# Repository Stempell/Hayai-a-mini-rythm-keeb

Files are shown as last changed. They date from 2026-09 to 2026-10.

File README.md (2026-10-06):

Banner3

Hayai is a Mini keyboard for shortcuts and playing rythm games. It features 4 magnetic hall effect switches (each with an rgb underglow LED) a rotary encoder and an 0.96" IPS display.
The display is connected by a FPC cable to a ZIF socket. custom footprints are in the kicad files.
The whole thing runs on a rp2040.

Here's how it looks:
Hayai

Hayai is desing around the Gateron magnetic jade air he dimensions but you can really use any magnetic switch you want, thanks to it's easy hotswap 

obraz

## Schematic
Zrzut ekranu 2026-09-25 191601

## PCB
obraz

dimensions of the pcb(and the acrylic plates) are roughly 84,5 x 48,7mm.

## Casing method
I took inspiration from the sayo device with the casing method with the pcb being sandwitched between the plates. I decided on a system where 4 holes will be occupied by screws attached from both sides to a female to female spacer, and the other 2 by dowel pins to prevent the plates from wobbling sideways.

Zrzut ekranu 2026-09-25 234834

The pcb sits inbetween the two middle plates with cutouts for components and pins

## Assembly
To assemble Hayai you'll need to follow these 4 simple steps:
1. Solder on all of the necesary components (you will have a bit less work to do if you choose pcba) The mcu can come with header pins pre-soldered on so you can make your job a bit easier for a like a dollar
2. Connect the display via the fpc cable with the panel facing upwards from the pcb and lay it flat on the board.
3. Sandwitch the pcb between the plates (look at the 3d model if you need some guidance) and put M3 dowel pins into the middle holes on the sides.
4. put M2 standoffs into the corner holes and screw them in with M2. this should hold the plates together. You can also add washers under the screws so it holds the plates better, M3 should fit.

Have fun! C:

## Bill of Materials

| # | Item | Quantity | Price | Link |
|---:|---|---:|---:|---|
| 1 | Custom PCB | 1 | ~$22.87 | [JLCPCB](https://jlcpcb.com/) |
| 2 | Acrylic plates | 4 | ~$18.04 | [Elecrow](https://www.elecrow.com/) |
| 3 | GATERON Magnetic Jade Air HE Switches | 4 | $15.00 | [GATERON](https://pl.aliexpress.com/item/1005005513800132.html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) |
| 4 | Keycaps of choice | 4 | $1.34 | [AliExpress](https://pl.aliexpress.com/item/4000473863693.html) |
| 5 | 0.96" IPS TFT ST7735 display | 1 | $1.62 | [BuyDisplay](https://www.buydisplay.com/0-96-inch-mini-color-tft-lcd-display-module-80x160-ips-tft-st7735) |
| 6 | EC11 20mm switch rotary encoder with mounting plates (the cap i chose fits the one with a plum handle) | 1 | $1.38 | [AliExpress](https://pl.aliexpress.com/item/1005007644083514.html) |
| 7 | Encoder cap of choice | 1 | $3.24 | [AliExpress](https://pl.aliexpress.com/item/1005008583446552.html) |
| 8 | Waveshare RP2350-Zero Mini Development Board Female | 1 | $5.79 | [Waveshare](https://www.waveshare.com/rp2350-zero.htm) |
| 9 | 1x9 pin header for microcontroller | 2 | $2.45 | [AliExpress](https://tinyurl.com/3yzm8hka) |
| 10 | DRV5056A4QDBZR (SOT-23-3) | 4 | $3.36 | [JLCPCB](https://jlcpcb.com/partdetail/TexasInstruments-DRV5056A4QDBZR/C2152902) |
| 11 | Brass standoffs (M2, 13mm) | 4 | $3.28 | [AliExpress](https://pl.aliexpress.com/item/1005012002279754.html) |
| 12 | Dowel pins (M3, 14mm) | 4 | $4.11 | [AliExpress](https://pl.aliexpress.com/item/4000473863693.html) |
| 13 | M2 screws, can also add washers | 4 |  |  |
| 14 | SK6812-MINI-E LEDs | 4 | $2.01 | [AliExpress](https://pl.aliexpress.com/item/1005008308801366.html) |

Subtotal : $84.40

Note that the pcb and plates were made around these specific parts. You can experiment and switch them out for different models but i don't guarantee it'll work

## BIll of materials for the pcba assembly

| Designator | Comment | Footprint | JLCPCB Part # | Manufacturer | Lib Type | Qty | Price |
|---|---|---|---|---|---|---|---|
| C17 | 10uF | 0402 | [C15525](https://jlcpcb.com/partdetail/16204-CL05A106MQ5NUNC/C15525)| Samsung Electro-Mechanics | Basic | 2 | $0.0512 |
| C18,C19,C20,C21,C22,C24,C25,C26,C27 | 0.1uF | 0402 | [C1525](https://jlcpcb.com/partdetail/1877-CL05B104KO5NNNC/C1525) | Samsung Electro-Mechanics | Basic | 18 | $0.0810 |
| R5 | 18Ω | 0402 | [C25084](https://jlcpcb.com/partdetail/25827-0402WGF180JTCE/C25084) | UNI-ROYAL (Uniroyal Elec) | Extended | 20 | $0.0480 |
| R7 | 10kΩ | 0402 | [C25744](https://jlcpcb.com/partdetail/26487-0402WGF1002TCE/C25744) | UNI-ROYAL (Uniroyal Elec) | Basic | 2 | $0.0068 |
| U4 | ZIF connector, 8-pin, 0.5mm | ZIF_connector8pin0,5mm | [C2856828](https://jlcpcb.com/partdetail/XUNPU-FPC_05FB8PH20/C2856828) | XUNPU | Extended | 2 | $0.3208 |
|

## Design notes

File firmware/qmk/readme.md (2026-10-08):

# hayai

hayai

*A short description of the keyboard/project*

* Keyboard Maintainer: [Wiktor Stepien](https://github.com/Stempell)
* Hardware Supported: *The PCBs, controllers supported*
* Hardware Availability: *Links to where you can find this hardware*

Make example for this keyboard (after setting up your build environment):

    make hayai:default

Flashing example for this keyboard:

    make hayai:default:flash

See the [build environment setup](https://docs.qmk.fm/#/getting_started_build_tools) and the [make instructions](https://docs.qmk.fm/#/getting_started_make_guide) for more information. Brand new to QMK? Start with our [Complete Newbs Guide](https://docs.qmk.fm/#/newbs).

## Bootloader

Enter the bootloader in 3 ways:

* **Bootmagic reset**: Hold down the key at (0,0) in the matrix (usually the top left key or Escape) and plug in the keyboard
* **Physical reset button**: Briefly press the button on the back of the PCB - some may have pads you must short instead
* **Keycode in layout**: Press the key mapped to `QK_BOOT` if it is available

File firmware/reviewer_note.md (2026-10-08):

Hi! i purposly did not add a finished firmware yet as i need the phisicaly bulid project to test the display, calibrate the switches, ect. I'll finish the firmware as soon as i am able to do so based on irl calibrations!

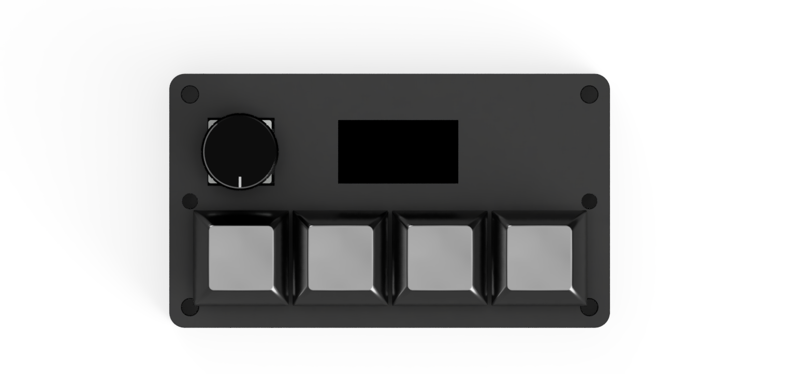
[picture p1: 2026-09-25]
Photos/Top view.png

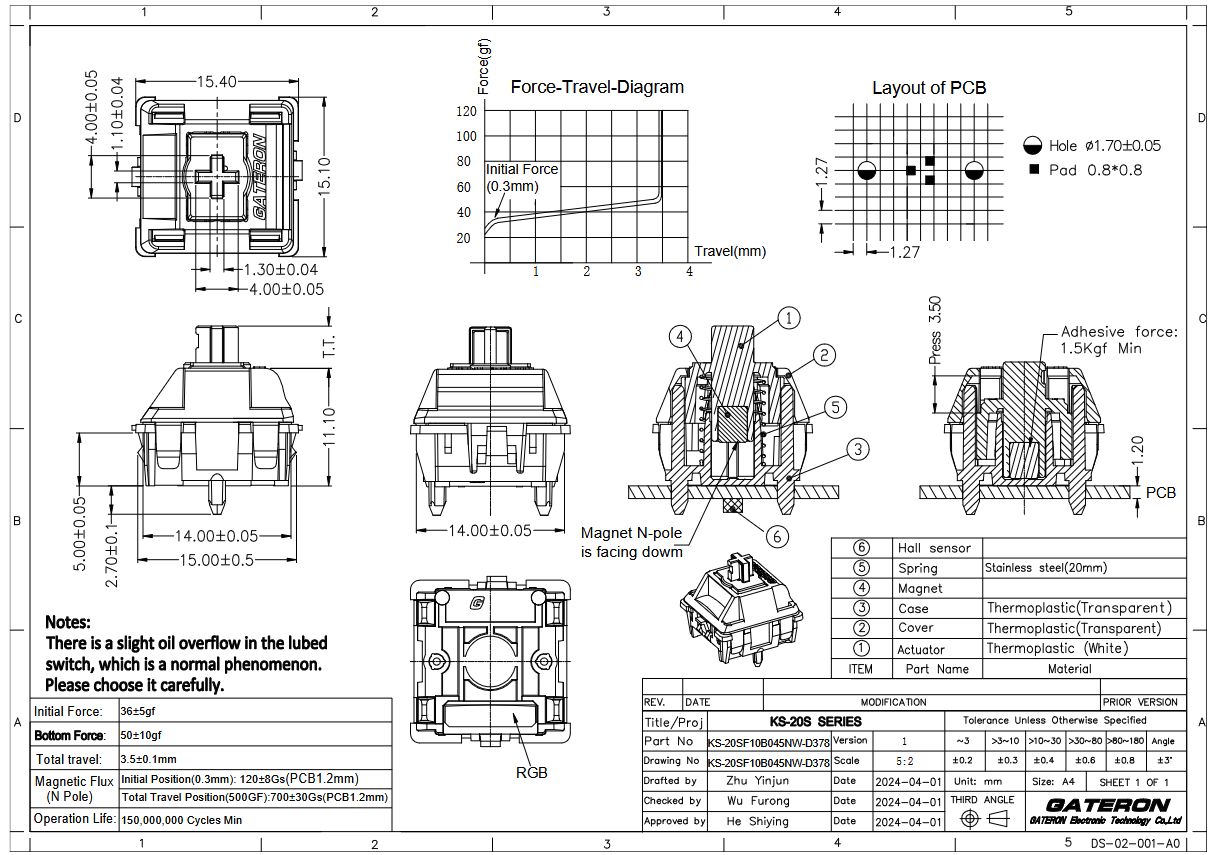
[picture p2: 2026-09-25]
Photos/Zrzut ekranu 2026-08-28 192311.png

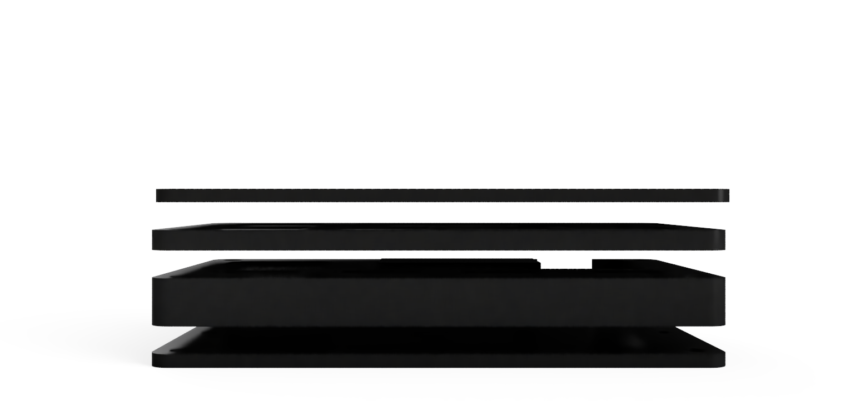
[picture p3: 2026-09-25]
Photos/plates1.png

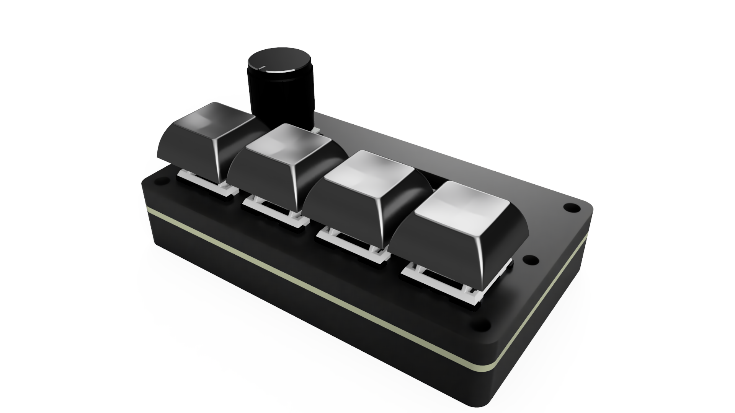
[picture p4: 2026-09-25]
Photos/Hayai.png

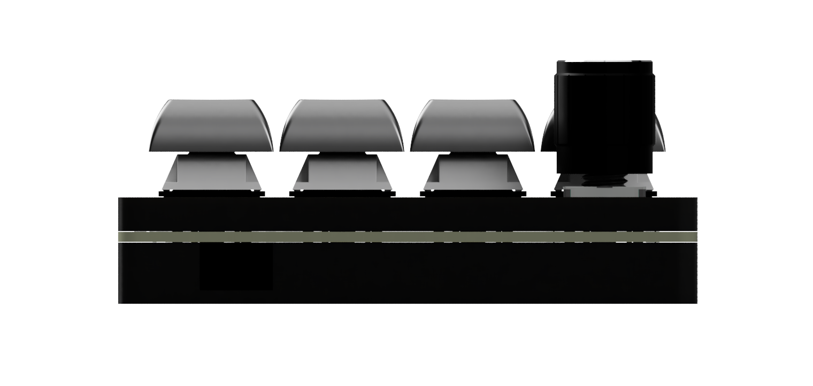
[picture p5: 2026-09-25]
Photos/Back view.png

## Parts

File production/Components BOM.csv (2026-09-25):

# | Item | Quantity | Price (USD) | Source
1 | Custom PCB | 1 | ~$22.87 | https://jlcpcb.com/
2 | Acrylic plates | 4 | ~$18.04 | https://www.elecrow.com/
3 | GATERON Magnetic Jade Air HE Switches | 4 | $15.00 | https://www.gateron.com/products/gateron-magnetic-jade-air-he-switch-set?VariantsId=11190
4 | Keycaps of choice | 4 | — | —
5 | 0.96" IPS TFT ST7735 display | 1 | $1.62 | https://www.buydisplay.com/0-96-inch-mini-color-tft-lcd-display-module-80x160-ips-tft-st7735
6 | EC11 20mm switch rotary encoder | 1 | ~$1.80 | —
7 | Encoder cap of choice | 1 | — | —
8 | Waveshare RP2350-Zero Mini Development Board Female | 1 | $5.79 | https://www.waveshare.com/rp2350-zero.htm
9 | 1x9 pin header for microcontroller | 2 | $2.45 | https://tinyurl.com/3yzm8hka
10 | DRV5056A4QDBZR (SOT-23-3) | 4 | $3.36 | https://www.digikey.com/en/products/detail/texas-instruments/DRV5056A4QDBZR/9692623
11 | Brass standoffs (2M, 13mm) | 4 | $3.28 | https://pl.aliexpress.com/item/1005012002279754.html
12 | Dowel pins (3M, 14mm) | 4 | $4.11 | https://pl.aliexpress.com/item/4000473863693.html
13 | M2 screws, can also add washers | 4 | — | —

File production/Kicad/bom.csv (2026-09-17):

Designator | Footprint | Quantity | Value | LCSC Part #
C17 | 0402 | 1 | 10uF
C18, C19, C20, C21, C22, C24, C25, C26, C27 | 0402 | 9 | 0.1uF
D1, D2, D3, D4 | LED_SK6812MINI-E_3.2x2.8mm_P1.5mm_ReverseMount | 4 | SK6812MINI-E
R5 | 0402 | 1 | 18Ω
R7 | 0402 | 1 | 10kΩ
SW1 | RotaryEncoder_Alps_EC11E-Switch_Vertical_H20mm_MountingHoles | 1 | RotaryEncoder_Switch_MP
U1 | Waveshare_RP2040-Zero_THT | 1 | ~
U4 | ZIF_connector 8 pin 0,5mm | 1 | ~
U5, U6, U7, U8 | SOT-23 | 4 | DRV5055A4xDBZxQ1

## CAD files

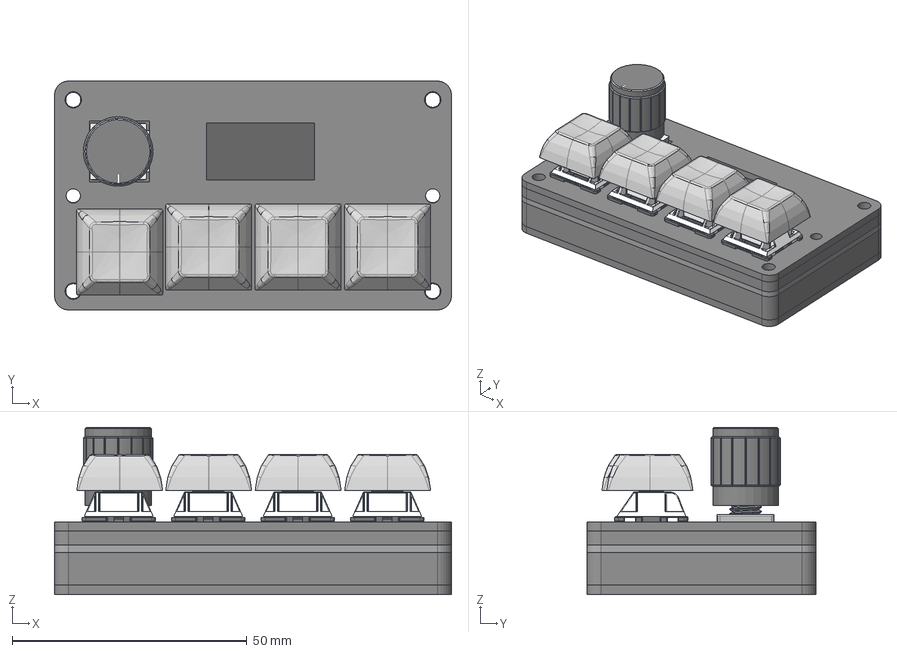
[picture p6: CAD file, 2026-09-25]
3D models/Hayai/Hayai full bulid V1.step
84.5 x 48.7 x 35.6 mm
C_0402_1005Metric x 10
R_0402_1005Metric x 2
MX_PCB x 4
Pin1 x 4
Pin2 x 4
Pin3 x 4
Pin4 x 4
EC11
SOT-23 x 4
HayaiAlt_copper
HayaiAlt_pad
HayaiAlt_via
HayaiAlt_silkscreen
HayaiAlt_silkscreen_1
HayaiAlt_soldermask
HayaiAlt_soldermask_1
HayaiAlt_PCB
keycap2 x 4
encoder cap

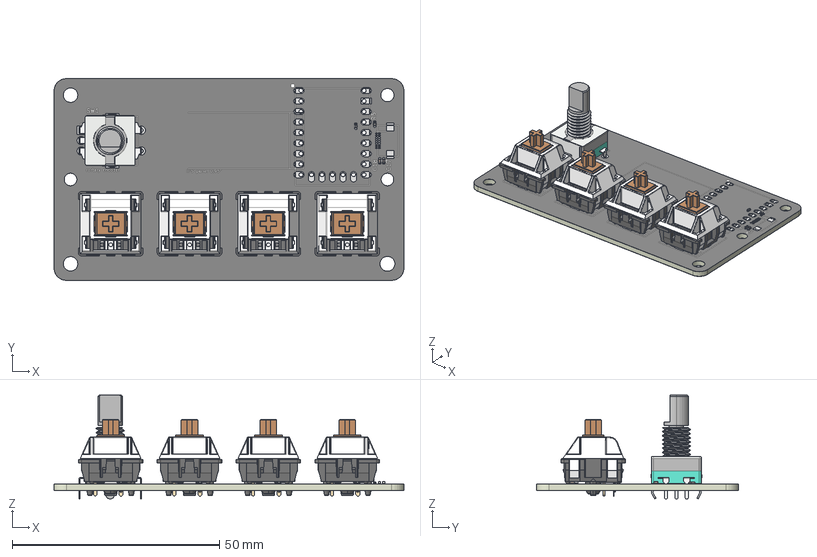
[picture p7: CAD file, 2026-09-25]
3D models/Hayai/pcb.step
84.5 x 48.7 x 25.1 mm
C_0402_1005Metric x 10
R_0402_1005Metric x 2
MX_PCB x 4
Pin1 x 4
Pin2 x 4
Pin3 x 4
Pin4 x 4
EC11
SOT-23 x 4
HayaiAlt_copper
HayaiAlt_pad
HayaiAlt_via
HayaiAlt_silkscreen x 2
HayaiAlt_soldermask x 2
HayaiAlt_PCB

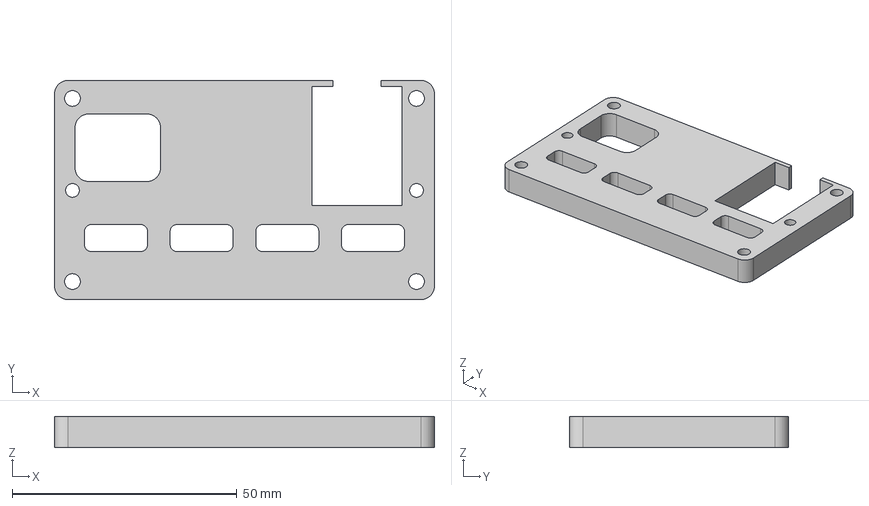
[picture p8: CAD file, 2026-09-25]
3D models/Plates/Hayai Lower midplate.step
84.5 x 48.7 x 7.00 mm

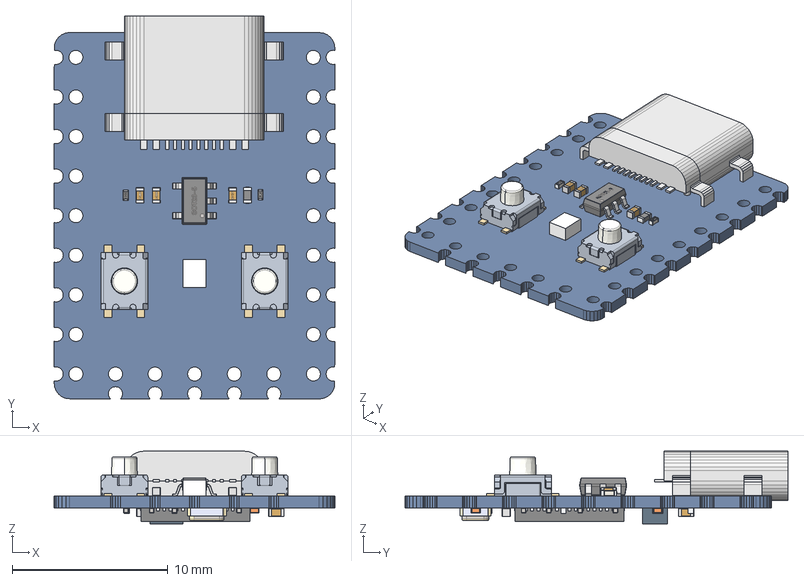
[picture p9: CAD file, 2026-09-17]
3D models/RP2350_Zero_step/RP2350-Zero.step
18.0 x 24.6 x 4.66 mm
Board
User_Library-TYPE-C-31-M-14
3_1_A x 7
User_Library-0201(0603M)_Cap x 12
ts-1185ec-a-e-a-1 x 2
Extruded x 2
User_Library-RES_0603-0201 x 8
User_Library-RP2350A
SOT23-5AND6_00 x 5
SOT23-5-14065_AF0
User_Library-SM2520-4
L0402

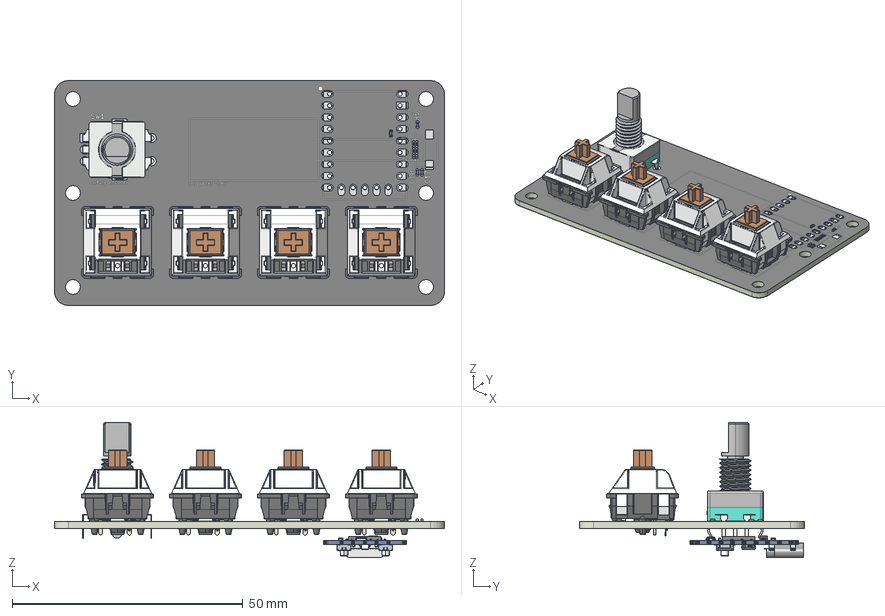
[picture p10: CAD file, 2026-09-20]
KiCad Files/hayai.step
84.5 x 48.7 x 29.3 mm
C_0402_1005Metric x 10
R_0402_1005Metric x 2
MX_PCB x 4
Pin1 x 4
Pin2 x 4
Pin3 x 4
Pin4 x 4
EC11
SOT-23 x 4
Board
User_Library-TYPE-C-31-M-14
3_1_A x 7
User_Library-0201(0603M)_Cap x 12
ts-1185ec-a-e-a-1 x 2
Extruded x 2
User_Library-RES_0603-0201 x 8
User_Library-RP2350A
SOT23-5AND6_00 x 5
SOT23-5-14065_AF0
User_Library-SM2520-4
L0402
HayaiAlt_copper
HayaiAlt_pad
HayaiAlt_via
HayaiAlt_silkscreen x 2
HayaiAlt_soldermask x 2
HayaiAlt_PCB

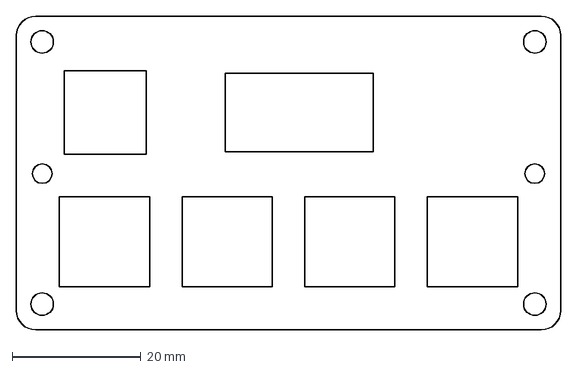
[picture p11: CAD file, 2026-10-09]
production/Plates dxf's/Top-plate.dxf
84.5 x 48.7 mm

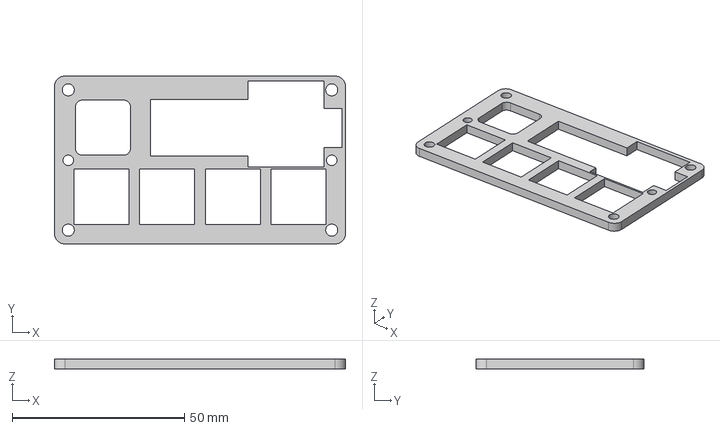
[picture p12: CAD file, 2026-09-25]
3D models/Plates/Hayai Upper midplate.step
84.5 x 48.7 x 3.00 mm

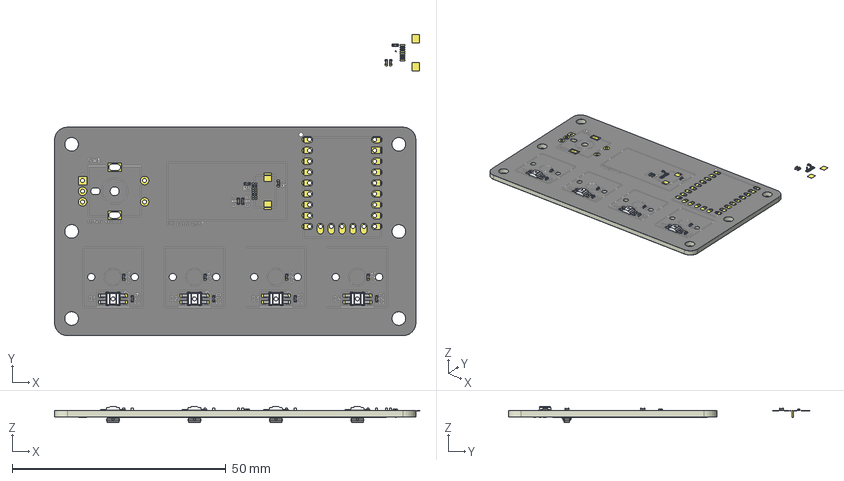
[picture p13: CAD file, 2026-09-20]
KiCad Files/.step
85.4 x 70.4 x 3.82 mm
C_0402_1005Metric x 12
Pin1 x 4
Pin2 x 4
Pin3 x 4
Pin4 x 4
R_0402_1005Metric x 3
SOT-23 x 4
HayaiAlt_copper
HayaiAlt_silkscreen x 2
HayaiAlt_soldermask x 2
HayaiAlt_PCB

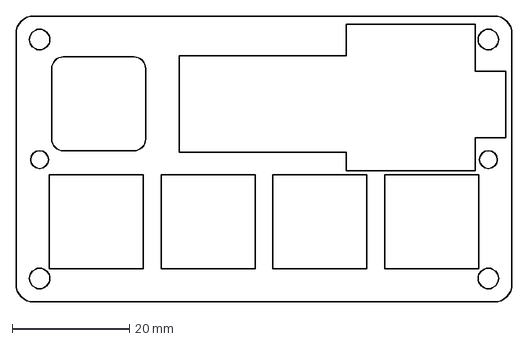
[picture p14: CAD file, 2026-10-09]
production/Plates dxf's/Upper-midplate.dxf
84.5 x 48.7 mm

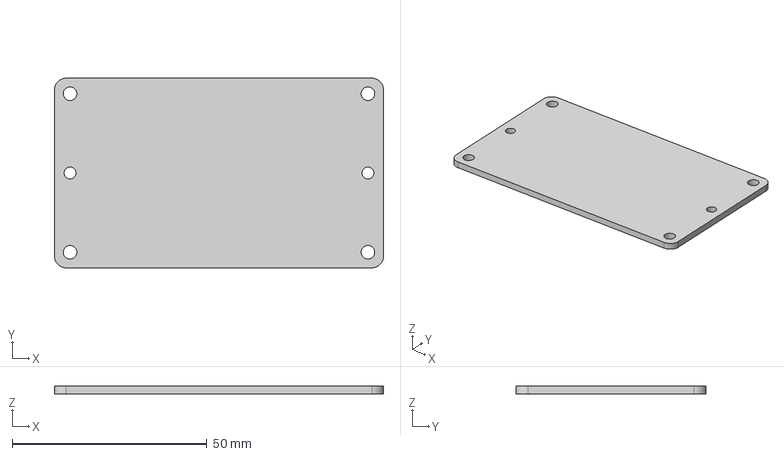
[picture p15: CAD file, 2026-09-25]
3D models/Plates/Hayai Bottom plate.step
84.5 x 48.7 x 2.00 mm

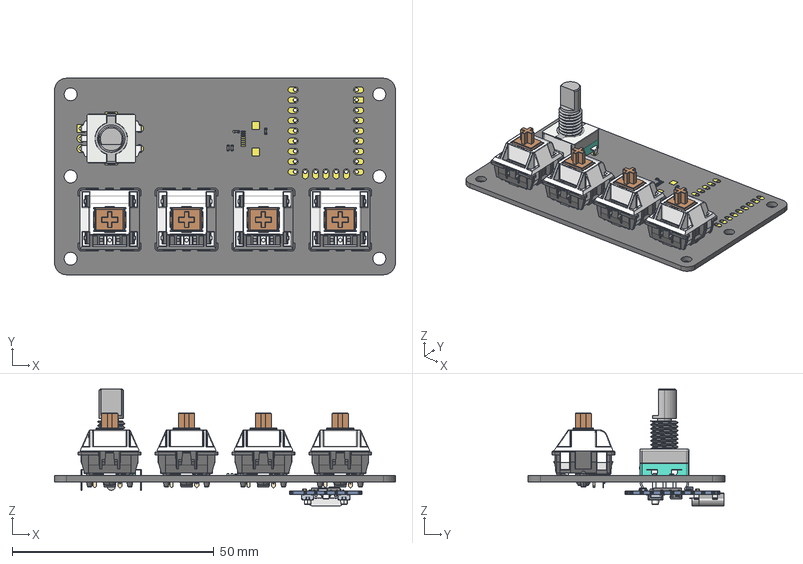
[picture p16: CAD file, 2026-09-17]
KiCad Files/HayaiAlt.step
84.5 x 48.7 x 29.0 mm
C_0402_1005Metric x 10
SW_Cherry_MX_PCB_cp x 4
Pin1 x 4
Pin2 x 4
Pin3 x 4
Pin4 x 4
R_0402_1005Metric x 2
ѽת±ძǷ
SOT-23 x 4
Board
User_Library-TYPE-C-31-M-14
3_1_A x 7
User_Library-0201(0603M)_Cap x 12
ts-1185ec-a-e-a-1 x 2
Extruded x 2
User_Library-RES_0603-0201 x 8
User_Library-RP2350A
SOT23-5AND6_00 x 5
SOT23-5-14065_AF0
User_Library-SM2520-4
L0402
HayaiAlt_copper
HayaiAlt_PCB

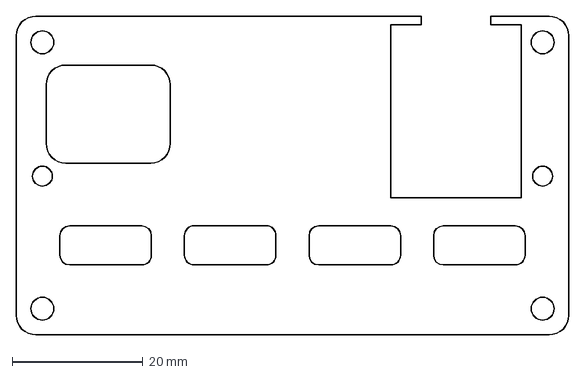
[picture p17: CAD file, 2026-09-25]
production/Plates dxf's/Lower-midplate.dxf
84.5 x 48.7 mm

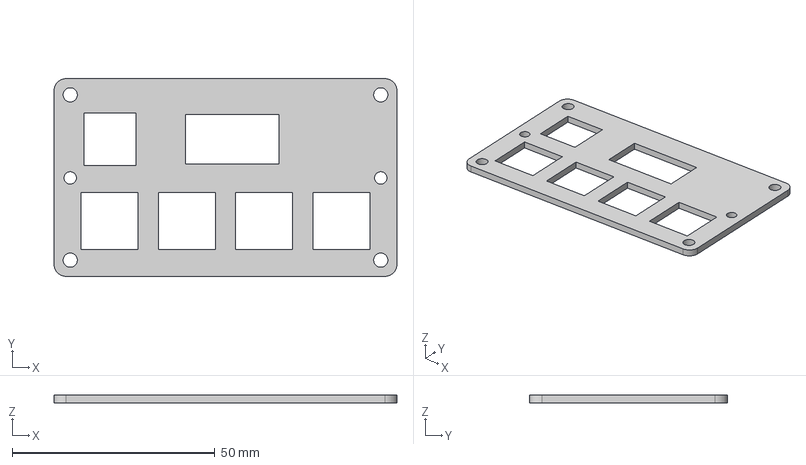
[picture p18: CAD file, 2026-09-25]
3D models/Plates/Hayai Top plate.step
84.5 x 48.7 x 2.00 mm

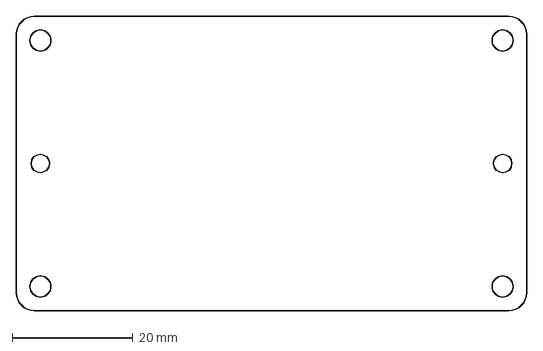
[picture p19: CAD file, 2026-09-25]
production/Plates dxf's/Bottom-plate.dxf
84.5 x 48.7 mm

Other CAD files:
3D models/Fusion_Source/Hayai full bulid V1.f3z
3D models/Fusion_Source/Plates/Hayai Bottom plate.f3d
3D models/Fusion_Source/Plates/Hayai Lower midplate.f3d
3D models/Fusion_Source/Plates/Hayai Top plate.f3d.f3d
3D models/Fusion_Source/Plates/Hayai Upper midplate.f3d
production/Plates dxf's/Bottom Plate.dxf
production/Plates dxf's/Lower Midplate.dxf
production/Plates dxf's/Top Plate.dxf
production/Plates dxf's/Upper Midplate.dxf

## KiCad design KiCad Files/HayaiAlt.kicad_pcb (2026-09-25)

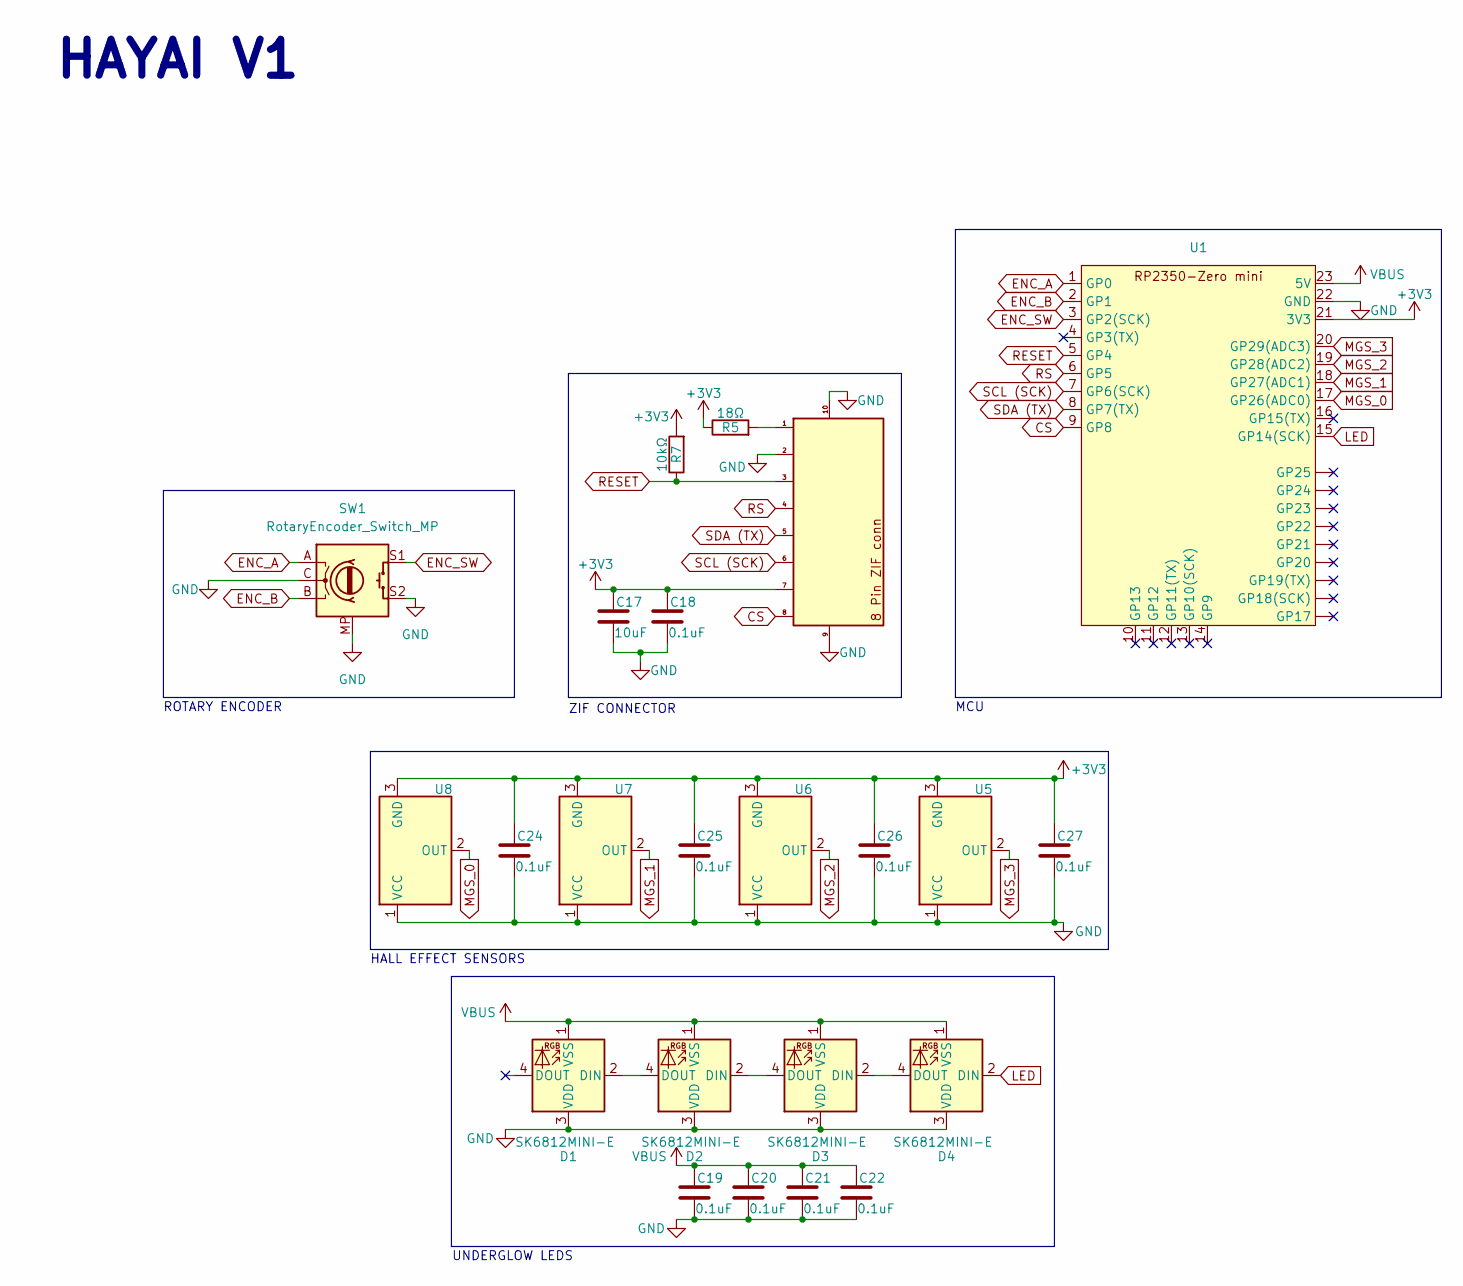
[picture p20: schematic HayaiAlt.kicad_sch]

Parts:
C17: 10uF; C_0402_1005Metric
C18, C19, C20, C21, C22, C24, C25, C26, C27: 0.1uF; C_0402_1005Metric
D1, D2, D3, D4: SK6812MINI-E; LED_SK6812MINI-E_3.2x2.8mm_P1.5mm_ReverseMount
R5: 18Ω; R_0402_1005Metric
R7: 10kΩ; R_0402_1005Metric
SW1: RotaryEncoder_Switch_MP; RotaryEncoder_Alps_EC11E-Switch_Vertical_H20mm_MountingHoles
U1: Waveshare_RP2040-Zero_THT
U4: ZIF_connector 8 pin 0,5mm
U5, U6, U7, U8: DRV5055A4xDBZxQ1; SOT-23

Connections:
+3V3: C17.1, C18.1, C24.1, C25.1, C26.1, C27.1, R5.1, R7.2, U1.21 (3V3), U4.7, U5.3 (GND), U6.3 (GND), U7.3 (GND), U8.3 (GND)
CS: U1.9 (GP8), U4.8
ENC_A: SW1.A, U1.1 (GP0)
ENC_B: SW1.B, U1.2 (GP1)
ENC_SW: SW1.S1, U1.3 (GP2(SCK))
GND: C17.2, C18.2, C19.2, C20.2, C21.2, C22.2, C24.2, C25.2, C26.2, C27.2, D1.3 (VDD), D2.3 (VDD), D3.3 (VDD), D4.3 (VDD), SW1.C, SW1.MP, SW1.S2, U1.22 (GND), U4.2, U4.9, U4.10, U5.1 (VCC), U6.1 (VCC), U7.1 (VCC), U8.1 (VCC)
LED: D4.2 (DIN), U1.15 (GP14(SCK))
MGS_0: U1.17 (GP26(ADC0)), U8.2 (OUT)
MGS_1: U1.18 (GP27(ADC1)), U7.2 (OUT)
MGS_2: U1.19 (GP28(ADC2)), U6.2 (OUT)
MGS_3: U1.20 (GP29(ADC3)), U5.2 (OUT)
unnamed: D1.2 (DIN), D2.4 (DOUT)
unnamed: D2.2 (DIN), D3.4 (DOUT)
unnamed: D3.2 (DIN), D4.4 (DOUT)
unnamed: R5.2, U4.1
RESET: R7.1, U1.5 (GP4), U4.3
RS: U1.6 (GP5), U4.4
SCL (SCK): U1.7 (GP6(SCK)), U4.6
SDA (TX): U1.8 (GP7(TX)), U4.5
VBUS: C19.1, C20.1, C21.1, C22.1, D1.1 (VSS), D2.1 (VSS), D3.1 (VSS), D4.1 (VSS), U1.23 (5V)

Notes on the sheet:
HAYAI V1
ZIF CONNECTOR
ROTARY ENCODER
UNDERGLOW LEDS
MCU
HALL EFFECT SENSORS

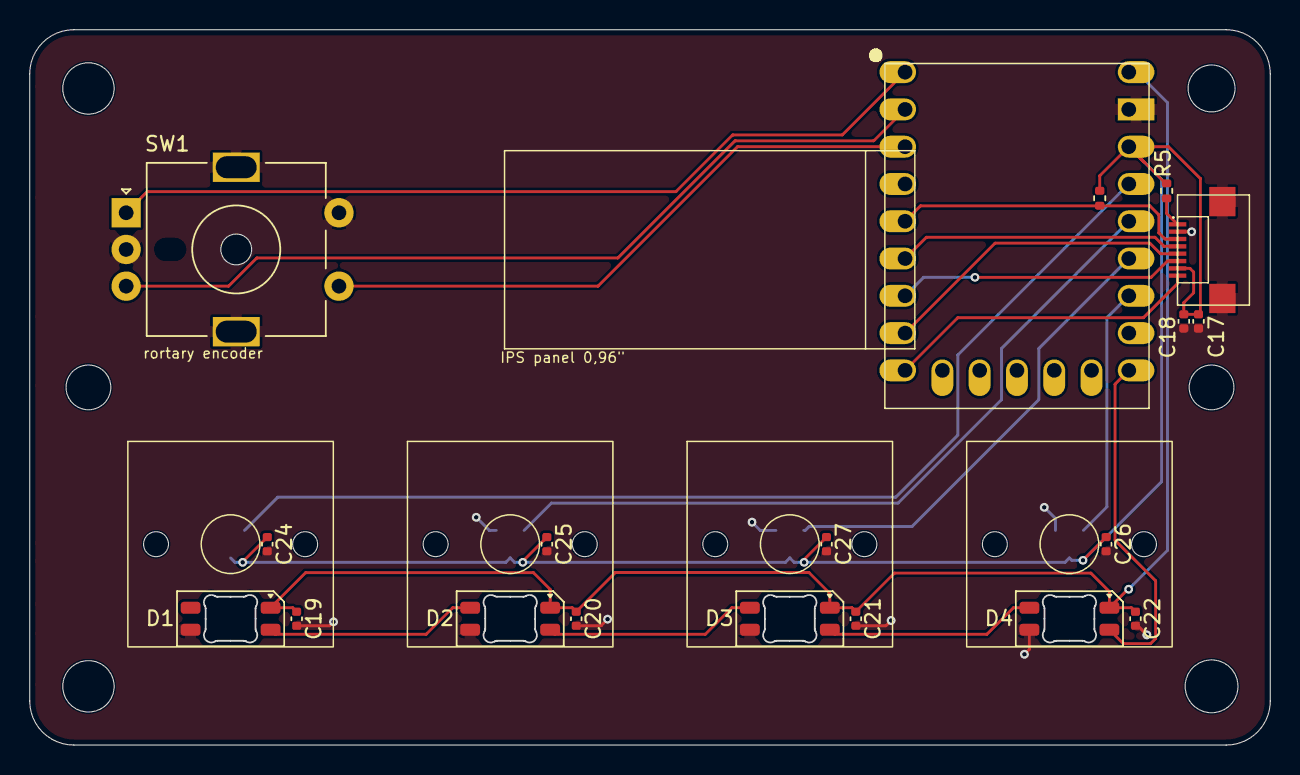
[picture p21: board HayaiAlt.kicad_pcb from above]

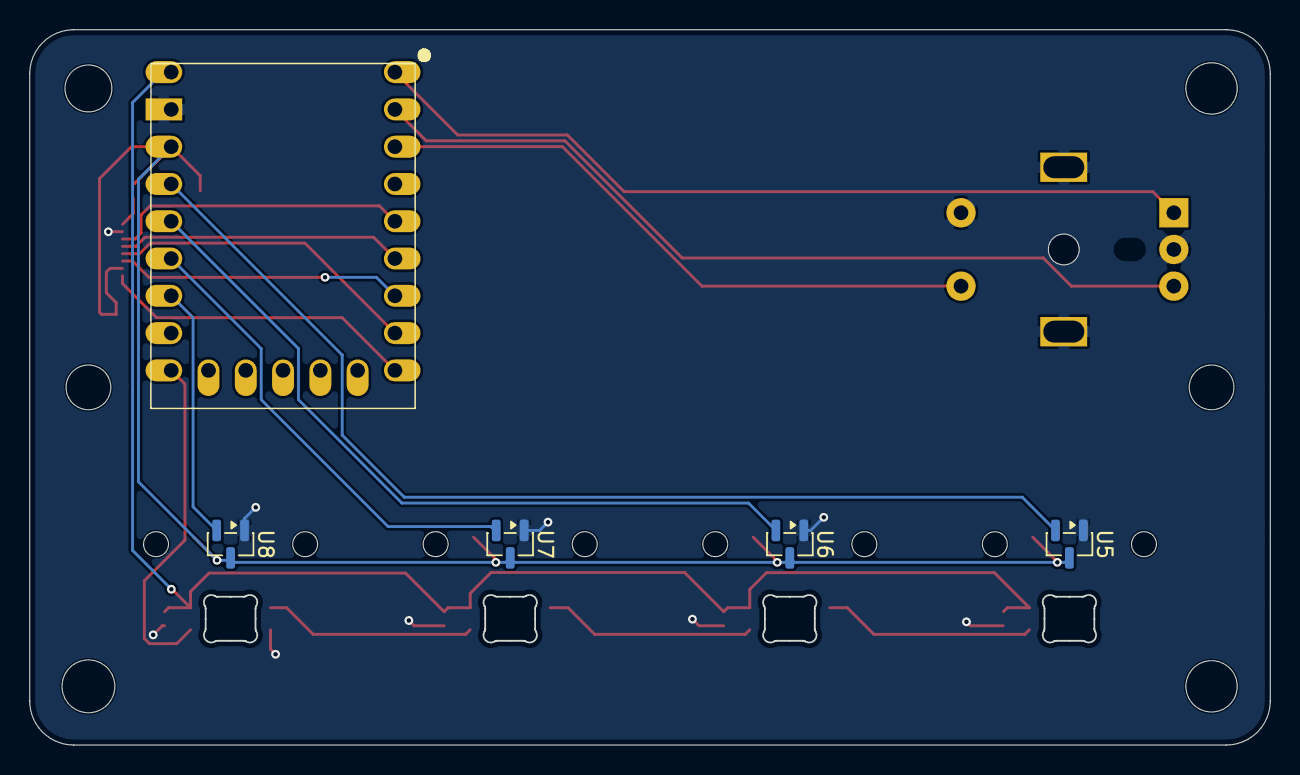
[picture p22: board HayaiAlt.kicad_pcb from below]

Board: 2 copper layers, 84.5 x 48.7 mm, 23 parts (5 on the bottom side), 20 nets.

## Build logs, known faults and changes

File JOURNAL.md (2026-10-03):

# Schematic and initial pcb design
After some trial, error and deviously long time looking for the right ips panel (asking guys on reddit came in handy as always) I completed the schematic and the initial pcb design.
   As for the parts i suppose they will remain unchanged but im sure the arrangement of them on the board will as i move on to designing the case for it, especially the ips panel bescause i just put it somewhere in the middle without a care in the world :P. I had to make my own footprint and symbol for the 8pin 0,5mm pich ZIF connector (i did not find any online :cc ) but at least now i know how to make these right? Arranging everything on the board is fairly easy given the space i have. Seriously - running a straight trace across the whole board has never been more refreshing after doing a pi pico devboard project!

obraz
obraz

Time spend - 6.5h 

# I fancy an upgrade, so lets start over 
After some thought, i decided to upgrade the regular mechanical switches
 to hall effect magnetic ones. That of course requires them to be hooked
 up to analog pins. But I already wired everything and stuff and the adc pins are on the opposite side of the board so it would really be a mess dragging them all the way so i decided to start over and redo the pcb. I also made a custom footprint for the switches i wanna use (the gateron magnetic jade Air HE's).

obraz

Time spend - 2.5h

# PC crashed, lost my work :C
so unfortunaly my pc crashed and i lost almost all work on the pcb, wchich was weird bescause i could have sworn i've been saving my progress regurarly. But we don't cry over spilled milk do we? I started over and made the pcb again it was easier as i just needed to redo it from memory. still have some silkscreen art to do tho.

obraz

Time spend - 3.5h

# Case plates finished!
And with that, the whole project, i think. I took inspiration for the casing method from the sayo device with the pcb "sandwitched" between these plates. mine will be made from acrylic and im still thinking about priting some designs on top of the top plate and maybe making the bottom plate transparent but we'll think about that later. Only thing left is some double checks, finishing up the repository and i think we're ready to submit! 
(btw i never told you but Hayai means swift in japanese :>)

obraz
obraz
obraz
obraz

Time spend - 1h

# Added mounting holes
i decided on a system where 4 holes will be occupied by screws attached from both sides to a female to female spacer, and the other 4 by dowel pins to prevent the plates from wobbling sideways. i'll adjust the hole sizes later when im ordering exact pins and screws

obraz
obraz

Time spend - 1h

# PCBA IS TOO EXPENSIVE
I looked over the pcb assembly costs and boy were they high. So high in fact, that it exceeds the max funding for the tier hayai falls into. to reduce assembly costs, i decided to use a microcontroller module instead of the chip. I used a rp2350 zero from waveshare and rerouted the whole board (and also expanded the borders a bit). Im a bit frustrated about the whole thing bescause the project was like 99% ready to submit and now i gotta do so many things all over again but it is what it is.

obraz
obraz

4.5h

# moving the zif connector and OnShape issues
### we're not sqishing the cable anymore 
Soooo i realised, that when assembling the whole thing, the fpc connector would only have like 1,5mm of space under the panel and that is WAAAY to little for it to not break so i had to lay it flat on the pcb and move the zif connector behind the mcu pins. 
 ### time for some bad news
When i tried to import the new board design into onshape for assembly, it spewed out an error that the step file coud not be translated. I thought to myself - fine just try again. Same thing happened so i started troubleshooting:
-gaps in edge-cuts? No
-corrupted models? Nope
-weird design? Nu uh, tried to import a plain rectangle and nothing changed.
-Kicad issues? Wrong, dropped a 3d model from a website, still couldn't translate
The worst thing about it was that it wasn't just the .step format that could not be translated by onshape. I tried stl, 3mf, gbl - the result was still the same. I ran out of ideas so i decided to switch to a different cad program (onshape failed to export the existing models too, so my work there is unaccesable now. Thanks ig) and face my worst fear - Autodesk Fusion. I hate this software for the dephts of my pure soul. this program is REALLY overengineered for me and my skills and all the tools, mechanics and functions are too complicated for me to handle and end up working against me and themselves. I had to redo all of the plates inside a program which I despise. I was so frustrated i forgot to log some hours. After a long work session I managed to finish them. You can see the results of my hard work below. Oh and we hit the 20 hour mark with this one!

obraz
obraz
obraz

Time spend - 5h

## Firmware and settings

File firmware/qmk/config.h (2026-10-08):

#pragma once

#define USB_POLLING_INTERVAL_MS 1

#define MATRIX_ROWS 1
#define MATRIX_COLS 5


#define HE_PINS { GP16, GP17, GP18, GP19 }
#define HE_KEY_COUNT 4

#define ENC_SW_PIN GP2

#define HE_ACTUATION_POS   60   // first press point
#define HE_RESET_POS       20   // below this = fully released, re-arms
#define HE_RT_PRESS_DELTA  10   // rapid-trigger re-press distance
#define HE_RT_RELEASE_DELTA 10  // rapid-trigger release distance
#define HE_MIN_RANGE       150  // min assumed (bottom - rest) in ADC counts
#define HE_FILTER_SHIFT    1    // EMA: f += (raw-f) >> shift

// Print raw/filtered ADC over the QMK console every 100 ms
#define HE_DEBUG

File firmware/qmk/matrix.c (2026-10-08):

#include "quantum.h"
#include "analog.h"
#include "timer.h"
#include "print.h"

static const pin_t he_pins[HE_KEY_COUNT] = HE_PINS;

typedef struct {
    int16_t rest;      // ADC value with key released
    int16_t bottom;    // largest ADC value seen (key fully pressed)
    int16_t filt;      // filtered ADC value
    uint8_t pos;       // travel 0..255
    uint8_t peak;      // highest pos since press
    uint8_t trough;    // lowest pos since release
    bool    armed;     // true once key has returned below RESET_POS
    bool    down;
} he_key_t;

static he_key_t keys[HE_KEY_COUNT];

static uint8_t calc_pos(he_key_t *k) {
    int32_t range = k->bottom - k->rest;
    if (range < HE_MIN_RANGE) range = HE_MIN_RANGE;
    int32_t p = ((int32_t)(k->filt - k->rest) * 255) / range;
    if (p < 0) p = 0;
    if (p > 255) p = 255;
    return (uint8_t)p;
}

static void update_key(he_key_t *k) {
    uint8_t pos = k->pos;
    if (!k->down) {
        if (pos <= HE_RESET_POS) {
            k->armed  = true;
            k->trough = pos;
        } else if (pos < k->trough) {
            k->trough = pos;
        }
        bool first = k->armed && pos >= HE_ACTUATION_POS;
        bool rt    = !k->armed && pos > HE_RESET_POS && (pos - k->trough) >= HE_RT_PRESS_DELTA;
        if (first || rt) {
            k->down  = true;
            k->peak  = pos;
            k->armed = false;
        }
    } else {
        if (pos > k->peak) k->peak = pos;
        if (pos <= HE_RESET_POS || (k->peak - pos) >= HE_RT_RELEASE_DELTA) {
            k->down   = false;
            k->trough = pos;
            k->armed  = (pos <= HE_RESET_POS);
        }
    }
}

void matrix_init_custom(void) {
    gpio_set_pin_input_high(ENC_SW_PIN);

    // Rest calibration: average 32 samples. Keep keys released at power-up.
    for (uint8_t i = 0; i < HE_KEY_COUNT; i++) {
        int32_t sum = 0;
        for (uint8_t n = 0; n < 32; n++) {
            sum += analogReadPin(he_pins[i]);
            wait_ms(1);
        }
        keys[i].rest   = sum / 32;
        keys[i].bottom = keys[i].rest + HE_MIN_RANGE;
        keys[i].filt   = keys[i].rest;
        keys[i].armed  = true;
    }
}

bool matrix_scan_custom(matrix_row_t current_matrix[]) {
    matrix_row_t row = 0;

    for (uint8_t i = 0; i < HE_KEY_COUNT; i++) {
        he_key_t *k  = &keys[i];
        int16_t  raw = analogReadPin(he_pins[i]);

        k->filt += (raw - k->filt) >> HE_FILTER_SHIFT;
        if (k->filt > k->bottom) k->bottom = k->filt;   // auto-learn bottom-out

        k->pos = calc_pos(k);
        update_key(k);
        if (k->down) row |= ((matrix_row_t)1 << i);
    }

    if (!gpio_read_pin(ENC_SW_PIN)) row |= ((matrix_row_t)1 << 4);

#ifdef HE_DEBUG
    static uint32_t last = 0;
    if (timer_elapsed32(last) > 100) {
        last = timer_read32();
        uprintf("HE raw/pos: %d/%u %d/%u %d/%u %d/%u\n",
                keys[0].filt, keys[0].pos, keys[1].filt, keys[1].pos,
                keys[2].filt, keys[2].pos, keys[3].filt, keys[3].pos);
    }
#endif

    bool changed = (current_matrix[0] != row);
    current_matrix[0] = row;
    return changed;
}

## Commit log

2026-09-06 Added Kicad and production files
    [Hayai.kicad_pcb, Hayai.kicad_sch, bom.csv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]
2026-09-06 added Kicad footprints for switches and ZIF connector
2026-09-09 up
    Added detailed information about the casing method and bill of materials.
2026-09-10 added plates image
2026-09-17 added files for the alt ver of hayai
    hayai pcb with a microcontroller module
    [EC11_Rotary_Encoder_Switched.step, HayaiAlt.kicad_pcb, HayaiAlt.kicad_sch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]
2026-09-20 added dxf's and step's for the plates and 3d model of hayai
    also some cleanups
    [.step, Bottom Plate.dxf, EC11_Rotary_Encoder_Switched.step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]
2026-09-20 added components bulid of hayai
    [Hayai component bulid (without caps).step]
2026-09-25 added production files and photos
    [Bottom-plate.dxf, Components BOM.csv, Hayai Bottom plate.step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]
2026-09-26 Add KiCanvas PCB badge to README
    Added a badge to view the PCB on KiCanvas.
2026-10-07 added firmware folder with reviewer note
    Expanded note on firmware completion and calibration.
2026-10-09 added fusion source files
    [Hayai Bottom plate.f3d, Hayai Lower midplate.f3d, Hayai Top plate.f3d.f3d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]
2026-10-18 added final ver kicad
